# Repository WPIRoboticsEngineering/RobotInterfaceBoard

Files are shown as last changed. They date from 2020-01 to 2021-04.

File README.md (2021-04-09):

# Arduino and the ESP32 Toolchain and Sloeber Eclipse

This is installed on the lab machines already. 

Download and install this, do not change any default values

 [Sloeber Eclipse install instructions](https://github.com/WPIRoboticsEngineering/RobotInterfaceBoard/blob/master/InstallEclipse.md)

 [Instructions to Open Projects in Eclipse](https://github.com/WPIRoboticsEngineering/RobotInterfaceBoard/blob/master/UseEclipse.md)
 
 # Start a Fresh Arduino Sketch in Sloeber Eclipse
[Create a Sketch with Git (STRONGLY recommended)](StartFreshSketch.md)

[Create a Sketch without Git (Discouraged)](StartFreshSketchNOGIT.md)

# Install VSCode+PlatformIO

[Instructions for setting up VSCode for use in RBE1001](https://github.com/WPIRoboticsEngineering/ZenVSCodeInstaller)

# Robot Interface Board

The Robot Interface Board (RIB) is a breakout board for the [ESP32-DevKitC Arduino module](https://www.digikey.com/product-detail/en/ESP32-DEVKITC-32D/1965-1000-ND/9356990/?itemSeq=353617778). The Dev Kit C is a reference design of the ESP32-WROOM-32 module which houses the WiFi and bluetooth Antenae. The ESP32-WROOM-32 module houses an ESP32 microcontroller. 

#### Datasheet

[Arduino compatiple DevkitC]( https://esp-idf.readthedocs.io/en/latest/get-started/get-started-devkitc.html)

[ESP32 Microcontroller High level Datasheet, 61 pages]( https://www.espressif.com/sites/default/files/documentation/esp32_datasheet_en.pdf)

[ESP32 Microcontroller Detailed Datasheet, 669 pages]( https://www.espressif.com/sites/default/files/documentation/esp32_technical_reference_manual_en.pdf)

[ESP32-DevKitC Arduino module wireing diagram ](https://dl.espressif.com/dl/schematics/esp32_devkitc_v4-sch-20180607a.pdf)

## PCB

Image of Board

## ESP32Dev Board PINMAP

Pin Functions

## IO Pin counts

There are 16 I/O pins availible for use in your programs with no external perpheral already using them.

There are 21 I/O pins availible for use in your programs including the 5 output only strapping pins.

There are 27 I/O pins availible for use in your programs by reusing the boot button pin, serial pins and i2c pins for other purposes. 

## User Button

There is a button connected to pin 0 and is accessible to the users code as a button. If you hold it whild pressing the reset button, however, it will hold the chip in bootloader mode and it will not run your code until the core is reset or programmed over the USB. Once your code starts, this button is availible for use as a button in your code and pressing it will not effect the opperation of the core after your program has started.  

## Pins to Never Use because they will disrupt programming and opperation:

GPIO 6-11    - These pins are hookups for external system flash and are used by the system flash. Unless you are extending the chips flash capibilities, do not use these. 

GPIO 1 and 3 -  these are used to program the device and are serial port pins.

## Output Only Pins 

These pins are strapping pins for the core, if pulled to a different state than the default not boot.

These are strapping pins and have to be in known states at the time of the chip booting. If you use them as outputs, be careful to note the the pull up or down resistor states for each. When using these pins make sure the weak-pull resistor will not interfeare with your intended opperation, and do not add additional weak-pull resistors.

```
GPIO 2  (pull down)
GPIO 5  (pull up)
GPIO 12 (pull down)
GPIO 13 (pull up)
GPIO 15 (pull up)
```
## Input Only pins (No Pull ups availible, no output modes)

34-39 are input only. They have no output modes at all. Analog input and digital input are availible. Note that there are no input pullups on these pins. 

```
GPIO 35
GPIO 34
GPIO 39
GPIO 36
```

## Availible as Both Input and Output (Pull ups availible)

```
GPIO 4
GPIO 14
GPIO 16-19
GPIO 21-23
GPIO 25-27
GPIO 32-33
```
## External Use pins

GPIO 0 is the boot pin, if held low during a reset it will prevent the device from booting

GPIO 1 and 3 are the serial port used for programming and print statements. This should not be used for user functions, but can be used if serial functionality is needed.

GPIO 13 Has an LED connected to it on the RIB

GPIO 22 and 21 have 4.7kOhm pullups on them and are connected to the Wii accessory port. These can be used with other i2c devices.
See: https://github.com/acamilo/RobotInterfaceBoard/issues/31

GPIO 27 Is connected to the Wii header as controller detect. When the controller is connected, this is pulled to 3.3v. It is open when the controller is not connected.  

## Availible Servo/PWM/AnalogWrite Pins

The ESP32 can generate up to 16 simultanious Servo signels. 

```
GPIO 4     
GPIO 5    
GPIO 12-19 
GPIO 21-23 
GPIO 25-27 
GPIO 32-33 
```

## Servos, PWM, tone() and Timers

The library ESP32Servo deals with all of the issues of cross allocation of the 4 timers and the associated PWM channels.

Use ESP32Servo objects to control the servo

Use the tone() function provided by ESP32Servo to make tones with PWM's

Use ESP32PWM objects to deal with the sound, or the tone implementation provided inside of ESP32Servo.

The library provides examples for each.

FYI: Inside the library it deals with the allocation and de allocation of timers and the associations of PWM's with a common time base together. What you need to understand is that there are 4 timers. Each timer can produce 4 PWM's *at the same frequency* but with independent duty cycles. That means you can have 16 hardware controlled PWM, so long as you have no more than 4 different frequencies. Esp32Servo keeps track of the allocation states of the users PWMs and dynamically allocates the correct ledC channel.

### Timer Interrupts

To use a timer interrupt, you will want to tell ESP32PWM not to allocate a specific timer. 

```
ESP32PWM::timerCount[0]=4;// this disables timer 0
ESP32PWM::timerCount[2]=4;// this disables timer 2
```
The timer needs to be disabled before allocating any PWM's. After disabling it will not be used in the PWM allocation system and can be used by a library or by the user as a raw timer for interrupts. 

See https://techtutorialsx.com/2017/10/07/esp32-arduino-timer-interrupts/

### ledc functions

DO NOT USE THESE! These are raw API level and are for the pros only. These pure C functions are part of the IDF and are provided for ESP32 programmers that are not using Arduino framework. ESP32Servo uses these functions internally, but manages the interactions between channels for you. The ledc functions spread PWM generation across the timers 0-4 using channels 0-15 in an unintuitive pattern:

```
/*
 * LEDC Chan to Group/Channel/Timer Mapping
** ledc: 0  => Group: 0, Channel: 0, Timer: 0
** ledc: 1  => Group: 0, Channel: 1, Timer: 0
** ledc: 2  => Group: 0, Channel: 2, Timer: 1
** ledc: 3  => Group: 0, Channel: 3, Timer: 1
** ledc: 4  => Group: 0, Channel: 4, Timer: 2
** ledc: 5  => Group: 0, Channel: 5, Timer: 2
** ledc: 6  => Group: 0, Channel: 6, Timer: 3
** ledc: 7  => Group: 0, Channel: 7, Timer: 3
** ledc: 8  => Group: 1, Channel: 0, Timer: 0
** ledc: 9  => Group: 1, Channel: 1, Timer: 0
** ledc: 10 => Group: 1, Channel: 2, Timer: 1
** ledc: 11 => Group: 1, Channel: 3, Timer: 1
** ledc: 12 => Group: 1, Channel: 4, Timer: 2
** ledc: 13 => Group: 1, Channel: 5, Timer: 2
** ledc: 14 => Group: 1, Channel: 6, Timer: 3
** ledc: 15 => Group: 1, Channel: 7, Timer: 3
*/
```

Note that timer 0 is used for ledc channels 0, 1, 8, 9 and that those channels will be all effected if the frequency on timer 0 is changed. If you are writing some code that deals with LEDC, then do not use any features of ESP32Servo nor any library that uses timers. 

## Availible DAC pins
```
GPIO 25
GPIO 26
```
These pins when used with analogWrite will produce an 8 bit analog value on the given pin. The value is from 0-3.3v mapped to 0-255 values. The api is to simply use analogWrite().

## Interrupt

For code examples: https://techtutorialsx.com/2017/09/30/esp32-arduino-external-interrupts/

Availible interruptable pins are all input pins.

# Development Computer Options  

## Option 1) A lab machine

Availible to all students. 

Note that the driver is installed on these computers

Note that Arduino with the ESP32 toolchain is already installed in C:\WPIAPPS\arduino-1.8.3\

Note Eclipse is installed on all workstations with the Sloeber plugin installed. 

##  Option 2) Personal Machine

### Supported for this class

Windows 10 Pro 

A user name with no " " in the file path. Generally it is safe to use your WPI username as the username on your computer.

Fresh install is genearlly reccomended every 6 months. Install disk are availible to students as a resource from the WPI Helpdesk.

OneDrive and Dropbox conflict with the install process and must be fully removed from the user file paths. 

### Unsupported OS's

MacOS is unsupported and only intermittantly working. Drivers have been an issue with programming our board, and virtualization of Windows within OSX is tested non-working. If you have Mac OSX please install a fresh copy of Windows 10 nativly and dual boot. 

Ubuntu 16.04 is unsupported but works well.

Ubuntu 18.04 is unsupported but works well with some creative directions following. This will take more effort and would require pre-existing proficency in Linux. If you have 18.04 please install Windows 10 or 16.04. 

### How to get Windows 10 as a Student for free from WPI

To get your student copy of Windows go here: 

https://onlinestore.wpi.edu/

Select windows 10, and download it. For students you get one copy and it is free. 

You can follow this tutorial to install it:

https://www.youtube.com/watch?v=aTVOTY93XXU

# Arduino Libraries
## HOWTO
For detailed instructions on how libraries work, see: https://www.arduino.cc/en/Guide/Libraries

Open Arduino and select Sketch->Libraries -> Manage Libraries
## Which Libraries

### 1001

ESP32Servo

ESP32Encoder

### 2001
Search for and install:

ESP32Servo

ESP32Encoder

Esp32SimplePacketComs

SimplePacketComs

### 2002
Search for and install:

ESP32Servo

ESP32Encoder

Adafruit_BNO055

Adafruit Unified Sensor

Esp32SimplePacketComs

SimplePacketComs

DFRobotIRPosition

# FAQ and troubleshooting

### "I dont see 'ESP32 Dev Module' as an option in Arduino when I try to select my board..."

* Use a lab machine. This will not be a problem on the lab machines. 

* You need to install the ESP 32 toolchain. See https://github.com/WPIRoboticsEngineering/RobotInterfaceBoard#personal-computer-install-windows--supported

### "I can compile the code but I do not have a serial port option in Arduino..."

* Ensure the driver installed https://github.com/WPIRoboticsEngineering/RobotInterfaceBoard#personal-computer-install-windows--supported

* If its a MAC, this is the issue that causes us to say MacOS is UNSUPPORTED. Install Windows https://github.com/WPIRoboticsEngineering/RobotInterfaceBoard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

* Make sure the USB Micro cable is a data cable, not just a crappy USB charging cable with no data lines. 

### "I can select the correct serial port, put it wont program or times out while programming..."

* Program an example script using Lab computer   (if this works have them re-download the pre-packaged arduino from https://github.com/WPIRoboticsEngineering/RobotInterfaceBoard#personal-computer-install-windows--supported ) 

* Is the serial moniter open? Close it and try again. 

* Did it program earlier? Unplug the USB and plug it back in.

* Hold Boot button and Strobe the enable button to set core into bootloader mode. Try to program. (If this helps, you are printing too much data to the serial port)

* Unplug everything from all IO (If this fixes it, check the pins and voltages, also check for diode dead-shorts check https://github.com/WPIRoboticsEngineering/RobotInterfaceBoard#pins-to-never-use )

* Check to see if the processor or regulator is HOT. If it is, a dead-short or over-voltage event occured and the device is dead forever. Replace. 

### "I can program it but it but it keeps rebooting over and over..."

* Null pointers are the #1 cause of this behavior, use print statements to isolate the point where it reboots and check for null pointers. This is the issue 9 out of 10 times. 

* Interrupt issues - Interrupts that access memory that is used by non-interrupt code without a mutex or semiphore. Try disabling the interrupt and if this fixed the reboot issue, then go ahead and implement the mutex locking. 

* Something may also be plugged into one of the off-limits pins, or your code is reconfiguring and messing up one of these pins. See: https://github.com/WPIRoboticsEngineering/RobotInterfaceBoard#pins-to-never-use 

### "This processor seems more complicated than the Uno and the Mega, why are we using it?"

* The ESP32 is a faster core at 260Mhz, vs the 16Mhz Uno. It is also dual-core.

* It has more perpherals needed for building robots, 16x 12 bit ADC, 2x DAC and 16 hardware encoder perpherals

* It has hardware and software that support WiFi for communications. 

* 32 bit processing with an FPU means complex math is possible on the microcontroller. 

* It is Arduino compatible for programming and Library support

* It is an open source design of the DevKit-C module, using an open soruce tool-chain

### "My eclipse if giving a 'Salt needs to be 8 bytes' error

This error comes from different versions of eclipse fighting over the ```$HOME/.eclipse/``` folder. This folder is where the passwords and keys are stored, however other newer copies of Eclipse use a slightly different format. The two copies fight over control of htat folder. To fix the problem close all copies of Eclipse/Sloeber and then erase that folder. Open Sloeber again and password storage will begin working. 

### I logged in with my credentials but it's not working (and I have 2fa enabled on my GitHub account)

You need to generate a token and use that in place of a password when storing credentials in Sloeber. 

For instructions on creating a token see: https://help.github.com/en/github/authenticating-to-github/creating-a-personal-access-token-for-the-command-line

Use your username as the login ID, and the token in the password field.

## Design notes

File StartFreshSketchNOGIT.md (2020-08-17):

# Create new Arduino sketch
## From an example
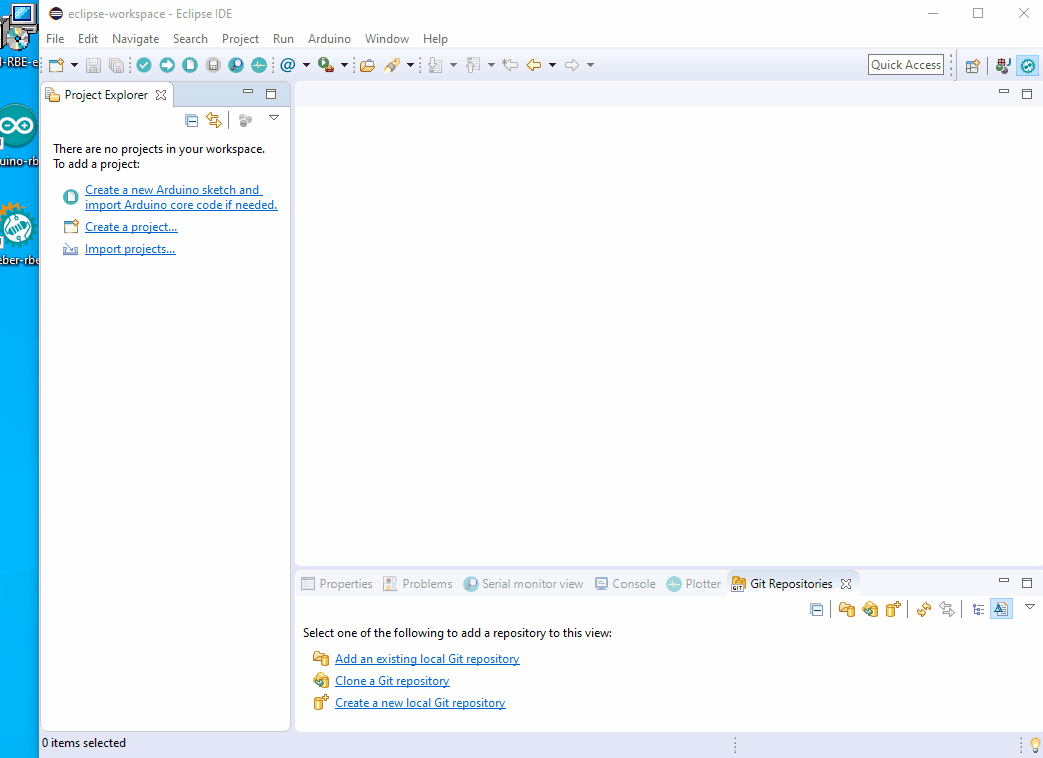
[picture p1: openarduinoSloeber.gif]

## Blank sketch


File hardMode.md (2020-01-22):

# HARD MODE

## Personal Computer install Linux   (Unsupported)

Ubuntu 18.04 Instructions:

[InstallToolchainOnUbuntu18-04.md](InstallToolchainOnUbuntu18-04.md)

Ubuntu 16.04 Instructions:
Installation instructions for Debian / Ubuntu OS
=================================================

- Install latest Arduino IDE from [arduino.cc](https://www.arduino.cc/en/Main/Software)
- Open Terminal and execute the following command (copy->paste and hit enter):

  ```bash
  sudo usermod -a -G dialout $USER && \
  sudo apt-get install git && \
  wget https://bootstrap.pypa.io/get-pip.py && \
  sudo python get-pip.py && \
  sudo pip install pyserial && \
  mkdir -p ~/Arduino/hardware/espressif && \
  cd ~/Arduino/hardware/espressif && \
  git clone https://github.com/espressif/arduino-esp32.git esp32 && \
  cd esp32 && \
  git checkout 1.0.3 && \
  git submodule update --init --recursive && \
  cd tools && \
  python3 get.py
  ```
- Restart Arduino IDE

- If you have Arduino installed to ~/, modify the installation as follows, beginning at `mkdir -p ~/Arduino/hardware`:

  ```bash
  cd ~/Arduino/hardware
  mkdir -p espressif && \
  cd espressif && \
  git clone https://github.com/espressif/arduino-esp32.git esp32 && \
  cd esp32 && \
  git checkout 1.0.3 && \
  git submodule update --init --recursive && \
  cd tools && \
  python3 get.py
  ```

## END Optional
-----

You most likely do not want to be here, but just in case you want to know how the sausage is made, here you go...

# Make Sure you have Java 8, *not 9, 10, 11 or 12*

Check your java version by opening CMD and typing 

```
java -version
```

and you should see:

```
java version "1.8.0_181"
Java(TM) SE Runtime Environment (build 1.8.0_181-b13)
Java HotSpot(TM) 64-Bit Server VM (build 25.181-b13, mixed mode)
```

If you see anything other than 1.8.something, remove Java then install it from:
  
https://www.java.com/en/download/manual.jsp  

Select this java on windows

## Install Eclipse and the Sloeber plugin (If the computer doesn't already have it)

Download the Eclipse Oxygen for C Development from here:

[https://www.eclipse.org/downloads/packages/release/2018-12/r](https://www.eclipse.org/downloads/packages/release/2018-12/r)

Select this Eclipse

Install Eclipse on C drive if using personal

```
C:\eclipse\
```

Once the install is done, open eclipse and go to the workbench. 




Open

```
Help->Eclipse Marketplace...
```

Search for Sloeber 



Set the workspace to Arduino mode. In the upper right hand corner there is a button with a little yellow plus sign, and when you hover over it is says "pen Perspective". Click that button. Select Arduino. 

Eclipse will restart to load the plugin.

#### Open the Arduino Preferences:

```
Arduino -> Preferences
```



And start by removing both of the default values for private Hardware and Private libraries:



Under Private Hardware Path, select New.. and search for (where you extracted Arduino)/hardware/ 

Mine looks like:
```
C:\WPIAPPS\arduino-1.8.3\hardware\
```

Under Private Library path, select New.. and search for your user library directory. It is usually in (your users home)\Documents\Arduino\libraries for Windows, or (your users home)/Arduino/libraries for Unix systems. You know you have the right one if the folder contains ESP32Servo, Esp32SimplePacketComs, SimplePacketComs, EspWii and WiiChuck Directories from the library install step above. Remember the location of this folder, it will be where you clone your code in a coming step. 

Mine looks like:
```
C:\Users\harrington\Documents\Arduino\libraries
```


# Doxygen and GraphViz
### Windows Doxygen and GraphViz

[Install Doxygen From these instructions](http://www.doxygen.nl/download.html)  or [the direct link](http://doxygen.nl/files/doxygen-1.8.15-setup.exe)

and [GraphViz from here](https://graphviz.gitlab.io/_pages/Download/Download_windows.html)

Then use [these instructins]( https://www.architectryan.com/2018/03/17/add-to-the-path-on-windows-10/) to set add GraphViz to the path

```
C:\Program Files (x86)\Graphviz2.38\bin
```

### Ubuntu Doxygen and GraphViz

```
sudo apt install doxygen
```
## After the native Doxygen, install the plugin

In eclipse

```
Help->Eclipse Marketplace...
```

Search for 

```
eclox
```

and install it. 

# Setup your project

 [Open Projects in Eclipse using the Eclipse instructions](https://github.com/WPIRoboticsEngineering/RobotInterfaceBoard/blob/master/UseEclipse.md)

# Troubleshooting

## arduinoPlugin\tools\make\make not found in PATH

There can be a currupted download to the Make tools, if this error comes up follow these instructions to correct it
Follow the instructions here : https://github.com/Sloeber/arduino-eclipse-plugin/issues/767

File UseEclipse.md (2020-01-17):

# First Install Eclipse/Sloeber/Doxygen 

 [See Eclipse install instructions in InstallEclipse.md](https://github.com/WPIRoboticsEngineering/RobotInterfaceBoard/blob/master/InstallEclipse.md)

# Set up an eclipse project

In eclipse, open 
```
Window->Show View-> Other -> Git ->Git Repositories
```


In the browser, Click the clone or download button in your new project and select clone (Be sure HTTPS not SSH is selected, unless you have set up your SSH keys).

 

Copy the clone URL.

In Eclipse, click the clone button: 

 

If your URL is still copied in the clip board, Eclipse will autofill most the clone information for the first step. Add your username and password.

 

Hit next and get to the Branch Selection window, change nothing and hit next.

Use the default checkout location. 

Hit Finish

## Open your project and start working

In Eclipse, Right click in the Project View and select 
```
New->Arduino Sketch
```

 

Un-check the default location, and seclect where you just cloned your code. Mine looks like: 

```
R:\RBE\gitRbe\RBE2001Code20
```

Give it the name:

```
RBE2001Code20
```
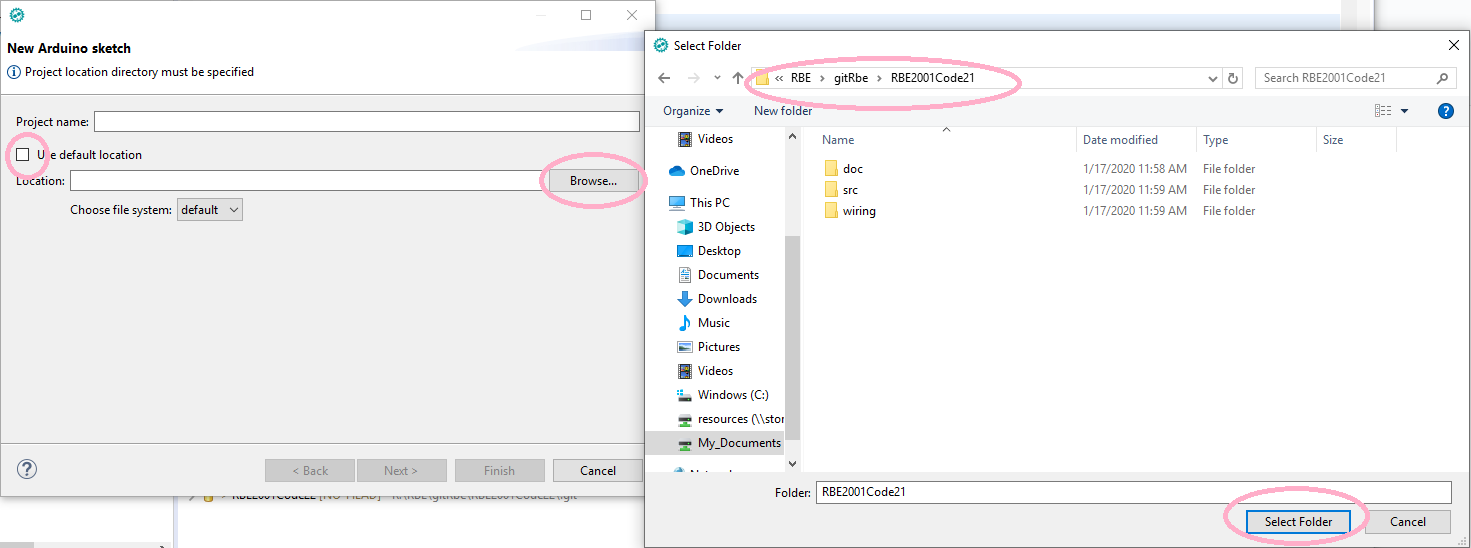
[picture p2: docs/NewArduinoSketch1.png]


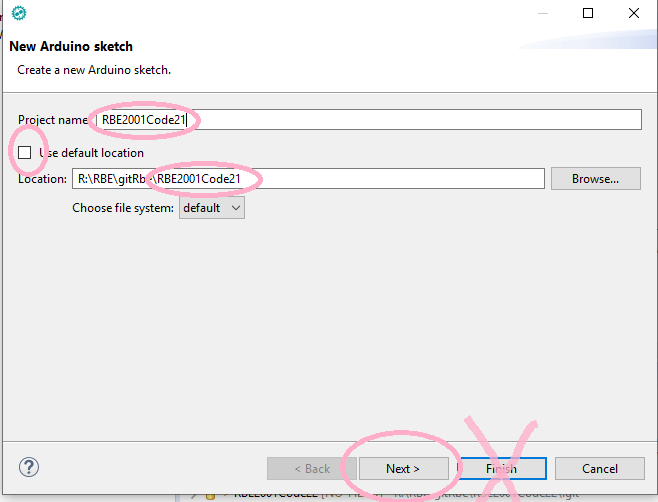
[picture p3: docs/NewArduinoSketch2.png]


Hit next then select the ESP32 toolchain. 



```
Board: ESP32 Dev Module
Upload Protocol: Default
Port (the port your device is on)
Core Debug Level: None
Flash Frequency 80mhz
Flash Mode: QIO
Flash Size: 4mb
Partition Scheme: Default
PSRAM: Disabled
Upload Speed: 921600
```

Then hit next and select Default ino file



Hit finish. 

Once the project shows up in Project Explorer tab, build index:



# Commit your changes

### Unfamiliar with Git?

run through this tutorial: https://resources.github.com/videos/github-best-practices/

Also check out this cheat sheet: http://overapi.com/git

### Familiar with Git?
When you make a change to any line of code, you should commit your changes. If you have worked for ~1 hour, then you should make a commit with a message describing your work. To do so, go back to 

Finally right click on your project
```
Team->Commit
```
Be sure to set the "Author" and "Committer" fields sould both contain the same data like this:
```
Kevin Harrington <harrington@wpi.edu>
```

Messages should consist of 60 charrectors of short description describing what changed, 2 new lines, then a t least one full sentance describing the justification for the change. If you have more than one file, only commit one at a time. using the "+" and "-" buttons in the Git Staging section. 

When you have chages to share with your team, first Right click on the repository and select "Pull". Merge any changes your team mates made and published to upstream. Then commit the merge (or commit nothing if the merge was clean) and push your changes to the upstream server.

Once you have pushed your changes, be sure to verify that they are on the GitHub.com website in Firefox. On your repository, go to
```
Insights->Network
```
and verify your changes are there. 

# Troubleshooting

## arduinoPlugin\tools\make\make not found in PATH

There can be a currupted download to the Make tools, if this error comes up follow these instructions to correct it
Follow the instructions here : https://github.com/Sloeber/arduino-eclipse-plugin/issues/767

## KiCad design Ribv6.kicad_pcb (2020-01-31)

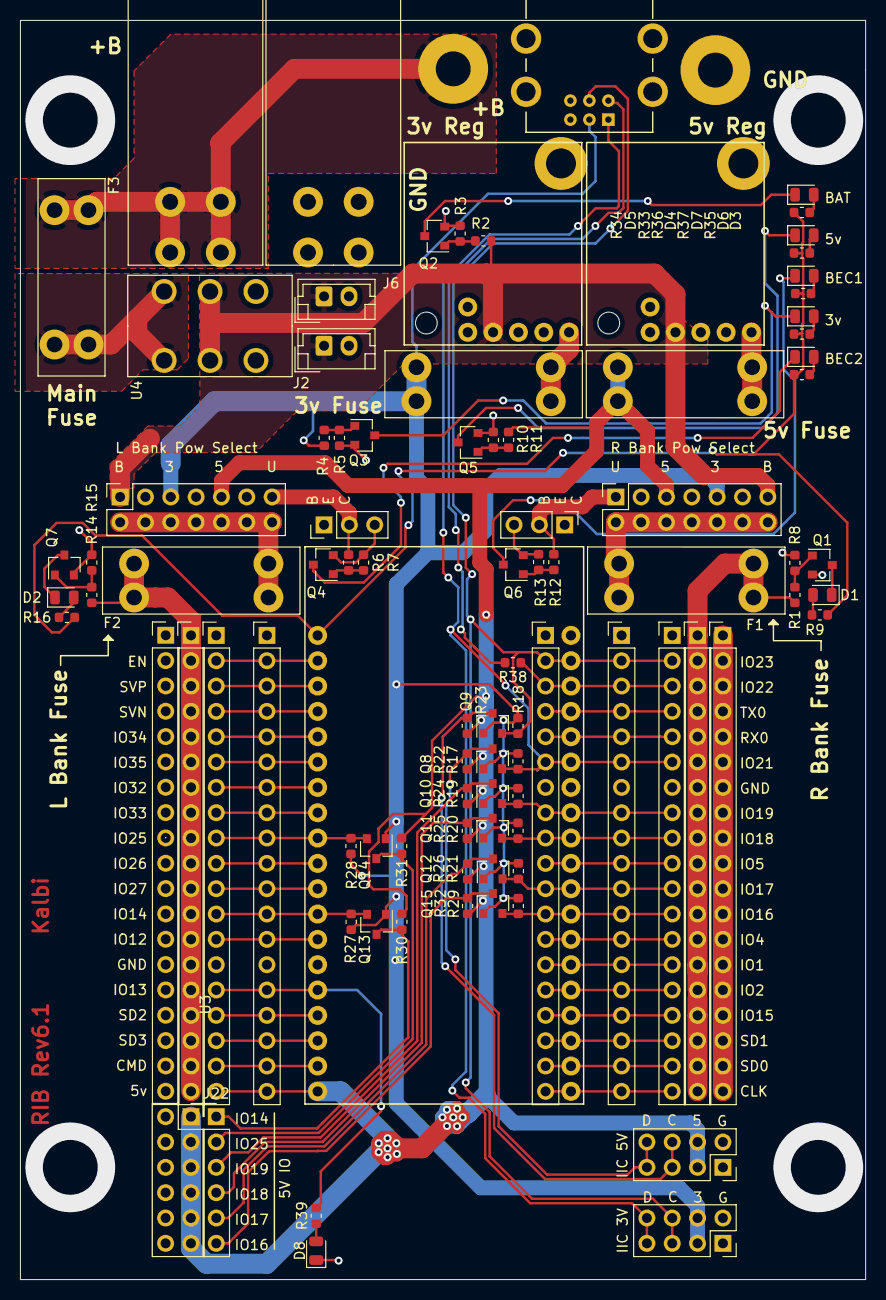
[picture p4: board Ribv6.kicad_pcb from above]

Board: 4 copper layers, 84.7 x 126.2 mm, 95 parts (0 on the bottom side), 80 nets.

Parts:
D1, D2, D3, D4, D5, D6, D7, D8: LED_Small; LED_0805_2012Metric
F1, F2, F3, F4, F5: Fuse; 3557-2
J1, J9: Conn_01x03; PinHeader_1x03_P2.54mm_Vertical
J2, J6: Conn_01x02_Female; JST_EH_B2B-EH-A_1x02_P2.50mm_Vertical
J3, J5, J7, J10, J13, J16, J19, J20, J21: Conn_01x19; PinHeader_1x19_P2.54mm_Vertical
J4, J8: Conn_02x07_Odd_Even; PinSocket_2x07_P2.54mm_Vertical
J11, J26: Conn_01x01_Male; P315100rH
J12, J24: Conn_01x01_Male; MountingHole_3.5mm_Pad
J14, J15: Conn_02x04_Odd_Even; PinSocket_2x04_P2.54mm_Vertical
J22: Conn_01x06; PinHeader_1x06_P2.54mm_Vertical
J23: Conn_02x06_Odd_Even; PinSocket_2x06_P2.54mm_Vertical
J25: Conn_01x06; CONN_WII
Q1, Q2, Q3, Q4, Q5, Q6, Q7, Q8, Q9, Q10, Q11, Q12, Q13, Q14, Q15: BSS138; SOT-23
R1, R2, R3, R4, R5, R6, R7, R8, R10, R11, R12, R13, R14, R15, R34: R_Small; R_0603_1608Metric
R9, R16, R33, R35, R36, R37, R39: 330; R_0603_1608Metric
R17, R18, R19, R20, R21, R22, R23, R24, R25, R26, R27, R28, R29, R30, R31, R32, R38: 10k; R_0603_1608Metric
U1, U2: polulu-3784-D36V28F7
U3: esp-devkit; ESP-DEVKIT
U4: DPDT_x2; GF-126-0327

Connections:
+3.3VA: R9.2, R16.2, R33.2, R34.2, R35.2, R36.2, R37.2, U3.3V3
+3V3: F4.2, J4.9, J8.5, J14.3, J14.4, J25.3, Q8.1, Q9.1, Q10.1, Q11.1, Q12.1, Q13.1, Q14.1, Q15.1, R4.2, R17.2, R18.2, R19.2, R20.2, R21.2, R27.2, R28.2, R29.2
+5V: F5.2, J4.5, J8.9, J13.19, J15.3, J15.4, J16.19, J23.1, J23.3, J23.5, J23.7, J23.9, J23.11, R10.2, R22.2, R23.2, R24.2, R25.2, R26.2, R30.2, R31.2, R32.2, U3.5V
+BATT: J2.1, J4.13, J6.1, J8.1, R2.2, U1.VIN, U2.VIN, U4.2, U4.5
GND: D8.1, J1.3, J2.2, J3.1, J3.2, J3.3, J3.4, J3.5, J3.6, J3.7, J3.8, J3.9, J3.10, J3.11, J3.12, J3.13, J3.14, J3.15, J3.16, J3.17, J3.18, J3.19, J6.2, J9.3, J10.1, J10.2, J10.3, J10.4, J10.5, J10.6, J10.7, J10.8, J10.9, J10.10, J10.11, J10.12, J10.13, J10.14, J10.15, J10.16, J10.17, J10.18, J10.19, J13.14, J14.1, J14.2, J15.1, J15.2, J16.14, J19.7, J20.7, J21.7, J23.2, J23.4, J23.6, J23.8, J23.10, J23.12, J24.1, J25.6, J26.1, Q1.2, Q2.2, Q3.2, Q4.2, Q5.2, Q6.2, Q7.2, R3.1, R5.1, R7.1, R8.1, R11.1, R13.1, R15.1, U1.GND, U2.GND, U3.GND
GPIO14: J13.12, J16.12, Q13.2, R27.1, U3.IO14
GPIO14_5: J22.1, Q13.3, R30.1
GPIO16: J19.12, J20.12, J21.12, Q15.2, R29.1, U3.IO16
GPIO16_5: J22.6, Q15.3, R32.1
GPIO17: J19.11, J20.11, J21.11, Q12.2, R21.1, U3.IO17
GPIO17_5: J22.5, Q12.3, R26.1
GPIO18: J19.9, J20.9, J21.9, Q11.2, R20.1, U3.IO18
GPIO18_5: J22.4, Q11.3, R25.1
GPIO19: J19.8, J20.8, J21.8, Q10.2, R19.1, U3.IO19
GPIO19_5: J22.3, Q10.3, R24.1
GPIO25: J13.9, J16.9, Q14.2, R28.1, U3.IO25
GPIO25_5: J22.2, Q14.3, R31.1
unnamed: D1.1, Q1.3
unnamed: D1.2, R9.1
unnamed: D2.1, Q7.3
unnamed: D2.2, R16.1
unnamed: D3.1, Q2.3
unnamed: D3.2, R35.1
unnamed: D4.1, Q3.3
unnamed: D4.2, R33.1
unnamed: D5.1, Q4.3
unnamed: D5.2, R34.1
unnamed: D6.1, Q5.3
unnamed: D6.2, R37.1
unnamed: D7.1, Q6.3
unnamed: D7.2, R36.1
unnamed: D8.2, R39.1
unnamed: F1.1, J4.2, J4.4, J4.6, J4.8, J4.10, J4.12, J4.14
unnamed: F2.1, J8.2, J8.4, J8.6, J8.8, J8.10, J8.12, J8.14
unnamed: F3.1, J11.1, J12.1
unnamed: F3.2, U4.3, U4.4
unnamed: F4.1, U1.VOUT
unnamed: F5.1, U2.VOUT
unnamed: J13.2, J16.2, U3.EN
unnamed: J13.3, J16.3, U3.SVP
unnamed: J13.4, J16.4, U3.SVN
unnamed: J13.5, J16.5, U3.IO34
unnamed: J13.6, J16.6, U3.IO35
unnamed: J13.7, J16.7, U3.IO32
unnamed: J13.8, J16.8, U3.IO33
unnamed: J13.10, J16.10, U3.IO26
unnamed: J13.11, J16.11, U3.IO27
unnamed: J13.13, J16.13, U3.IO12
unnamed: J13.15, J16.15, R39.2, U3.IO13
unnamed: J13.16, J16.16, U3.SD2
unnamed: J13.17, J16.17, U3.SD3
unnamed: J13.18, J16.18, U3.CMD
unnamed: J19.3, J20.3, J21.3, R38.1, U3.IO22
unnamed: J19.4, J20.4, J21.4, U3.TX0
unnamed: J19.5, J20.5, J21.5, U3.RX0
unnamed: J19.10, J20.10, J21.10, U3.IO5
unnamed: J19.13, J20.13, J21.13, U3.IO4
unnamed: J19.14, J20.14, J21.14, U3.IO1
unnamed: J19.15, J20.15, J21.15, U3.IO2
unnamed: J19.16, J20.16, J21.16, U3.IO15
unnamed: J19.17, J20.17, J21.17, U3.SD1
unnamed: J19.18, J20.18, J21.18, U3.SD0
unnamed: J19.19, J20.19, J21.19, U3.CLK
unnamed: Q1.1, R1.1, R8.2
unnamed: Q2.1, R2.1, R3.2
unnamed: Q3.1, R4.1, R5.2
unnamed: Q4.1, R6.1, R7.2
unnamed: Q5.1, R10.1, R11.2
unnamed: Q6.1, R12.1, R13.2
unnamed: Q7.1, R14.1, R15.2
unnamed: U4.1, U4.6
Rail1: F1.2, J5.1, J5.2, J5.3, J5.4, J5.5, J5.6, J5.7, J5.8, J5.9, J5.10, J5.11, J5.12, J5.13, J5.14, J5.15, J5.16, J5.17, J5.18, J5.19, R1.2
Rail2: F2.2, J7.1, J7.2, J7.3, J7.4, J7.5, J7.6, J7.7, J7.8, J7.9, J7.10, J7.11, J7.12, J7.13, J7.14, J7.15, J7.16, J7.17, J7.18, J7.19, R14.2
SCL_5: J15.5, J15.6, Q9.3, R23.1
SCL_33: J14.5, J14.6, J19.2, J20.2, J21.2, J25.4, Q9.2, R18.1, U3.IO23
SDA_5: J15.7, J15.8, Q8.3, R22.1
SDA_33: J14.7, J14.8, J19.6, J20.6, J21.6, J25.1, Q8.2, R17.1, U3.IO21
UBEC1: J1.2, J4.1, R12.2
UBEC2: J8.13, J9.2, R6.2
prez: J25.2, R38.2

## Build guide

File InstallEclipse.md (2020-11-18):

# Easy Mode
Download and install these, do not change any default values

## [Officially Supported Choice] 
### Windows 10 Stand Alone install

Requirements: Windows 10 on x86_64 with 16gb Ram

Development Environment: [Sloeber Windows Installer 0.3.2](https://github.com/WPIRoboticsEngineering/ESP32ArduinoEclipseInstaller/releases/download/0.3.2/WPI-RBE-esp32-0.3.2.exe)

Driver: [Esp32 Driver Windows](https://github.com/WPIRoboticsEngineering/ESP32ArduinoEclipseInstaller/releases/download/0.0.0/CP210x_Universal_Windows_Driver.zip)

Unzip the contents.

Open the folder on your disk and run

```
CP210xVCPInstaller_x64.exe
```

## [Unofficially supported] 
### Linux Bundled Sloeber

Development Environment: [Sloeber Linux Stand Alone](https://github.com/WPIRoboticsEngineering/ESP32ArduinoEclipseInstaller/releases/download/0.0.0/linux-eclipse-esp32.sh)

## [Unofficially supported] 
### MacOS 10.14 or earlier Bundled Sloeber

We reccomend you install Windows 10 with boot camp. If you want to try the native MacOS version, here be dragons.

Development Environment: [Sloeber MacOS Stand Alone](https://github.com/WPIRoboticsEngineering/ESP32ArduinoEclipseInstaller/releases/download/0.1.9/sloeber-MacOS-Esp32.zip)

Driver: [Esp32 Driver MacOS](https://github.com/WPIRoboticsEngineering/ESP32ArduinoEclipseInstaller/releases/download/0.0.0/SiLabsUSBDriverDisk.dmg)

## Thats it, its all installed and configured

You are done, do not continue, go here:

## Start a Fresh Arduino Sketch
[Create a Sketch with Git ](StartFreshSketch.md)

[Create a Sketch no version control](StartFreshSketchNOGIT.md)
 
 Or just open Arduino RBE config on your desktop and use as normal. 

# HARD MODE

## [Unsupported, not reccomended] 
### MacOS 10.15+ Bundled Sloeber

We reccomend you install Windows 10 with boot camp. If you want to try the native MacOS version, here be dragons.

#### 1) Install Standard Java 8

First install Java: https://www.java.com/en/download/manual.jsp

#### 2) Install the OpenJDK Framework

https://github.com/AdoptOpenJDK/openjdk8-binaries/releases/download/jdk8u262-b10/OpenJDK8U-jdk_x64_mac_hotspot_8u262b10.pkg

GUI installation

Instructions for running an interactive installation using the macOS PKG installer.

1. Download the .pkg file.

2. Navigate to the folder that contains the file and open it to launch the installation program or drag the icon to your Application folder.

3. The Introduction screen indicates the target location for the installation, which you can change later in the install process. Click Continue.

4. Read the license, click Continue and accept the license if you are happy with the terms.

5. Change the target location for the installation. Click Install to complete the installation.

#### 3) Install Sloeber and the Driver

Development Environment: [Sloeber MacOS Stand Alone](https://github.com/WPIRoboticsEngineering/ESP32ArduinoEclipseInstaller/releases/download/0.1.9/sloeber-MacOS-Esp32.zip)

Driver: [Esp32 Driver MacOS](https://github.com/WPIRoboticsEngineering/ESP32ArduinoEclipseInstaller/releases/download/0.0.0/SiLabsUSBDriverDisk.dmg)

## From scratch setup

I am almost sure you do not want this, but in case you are curious how those bundles are created in the first place you can look at [hardMode.md](hardMode.md)

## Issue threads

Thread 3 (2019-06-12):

Update power system for RIB

madhephaestus, 2019-06-12:
Update of rib need not maintain the board outline nor bolt pattern. Use the check boxes to keep track of progress.
@acamilo

- [x] Bolt holes should be 5.5mm diameter, keepaway of 9mm diameter
- [x] Bolt holes should lie on a 25mm grid
- [x] Add a rail, one unit inboard of the Devkit-c, to allow the narrow version of the module to be used
- [x] 7.5 - 18 v battery in, with a solder lug and
- [x] banana plug for power and ground (RAW)
- [ ] Side of board with the banana plugs should be ~80mm, with the bolt holes at 75mm center-to-center
- [x] A 5v 2 amp switching converter, RAW (post fuse) in ,  powering the ESP (SYSTEM 5)
- [x] 2 x external power converter ports, RAW (post fuse) in , regulated out, connectors to match the OTS switch mode we use (EXT REG)
- [x] 3.3v, 2 amp sensor power, replace the 3.3 from ESP pins (SENSOR 3.3)
- [x] replace the 3.3 from ESP pins with SENSOR 3.3
- [x] both rails should have a power switch jumper bank, from rail to: SYSTEM 5,RAW,EXT REG,SENSOR 3.3
- [ ] each power bank should have an indicator led for each 4 power rails, total 8 leds, physically close to the associated rail.
- [ ] New Images, use the same names to keep documentation links consistent
- [x] connect GPIO 0 (BOOT) to the IO
- [x] connect RST to IO
- [x] add a 5v level shiftier to i2c and expose the 5v side in a header
- [x] add 5v level shifted (bi directional) versions of 19,18,17,16,25,14
- [x] 5v bank should be similar to io bank, 8x3 0.1 in female headers, signel,  (SYSTEM 5), ground
- [ ] add SS on the outer edge of the IO, improve readability

madhephaestus, 2019-06-13:
@acamilo please use this issue number in your commit messages to link them here

acamilo, 2019-06-24:
- [ ] 7/1/2019 Send prototype to pcb house
- [ ] 7/8/2019 Begin assembly, testing, bugfixes
- [ ] 7/15/2019 Send out next rev
- [ ] 7/22/2019 assy,testing rev2
- [ ] 7/29/2019 start full turn order of 30

acamilo, 2019-06-24:
each power bank should have an indicator led for each 4 power rails, total 8 leds, physically close to the associated rail.

Why do we need a power indicator for each rail and each voltage?

madhephaestus, 2019-06-24:
@acamilo the power indicators were asked for specifically.

Closed 2020-01-17.

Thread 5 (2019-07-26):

Rib V2 needs a switch

madhephaestus, 2019-07-26:
As an extension of #3

madhephaestus, 2019-07-27:
the switch should disconnect the battery from the rest of the circuit. When off, the batter should not drain.

acamilo, 2019-10-15:
ok

Closed 2020-01-17.

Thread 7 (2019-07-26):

Rib v2 Banana Jacks should be color coded, red for Positive

madhephaestus, 2019-07-26:

acamilo, 2019-10-15:
This is a change to the BOM. The test board was populated with black because that is what was ordered.

madhephaestus, 2019-10-15:
commit the change to the BOM and close the issue

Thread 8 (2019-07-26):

BEC headers should match the BEC

madhephaestus, 2019-07-26:
on header should be 2 pin keyed female, the other a 3 pin male.

acamilo, 2019-10-15:
I can not source the 2 pin keyed connectors.

madhephaestus, 2019-10-15:
https://www.pololu.com/product/2181

madhephaestus, 2019-10-15:
also https://www.digikey.com/catalog/en/partgroup/rcy-series/25502

acamilo, 2019-10-18:
Free hanging, goes on the end of a cable.

acamilo, 2019-10-18:
Also, the 2181 is a "male" but it is the end thats on the UBEC side.

acamilo, 2019-10-18:
i recomend an adapter cable to something sensable.

acamilo, 2019-10-18:
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
like this JST

acamilo, 2019-10-18:
I move forward with a PTH JST style connector and you have some students make and heat shrink a few short cables.

madhephaestus, 2019-10-18:
just leave unpopulated and we can solder one of these on: https://www.pololu.com/product/2180

acamilo, 2019-10-18:
I don't like danglers

acamilo, 2020-01-17:
If we're going with a dangler then this issue is closed.

Closed 2020-01-17.

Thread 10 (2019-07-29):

Rib v2 D1 is always off, regardless of fuse and jumper

madhephaestus, 2019-07-29:

acamilo, 2019-10-15:
There is a problem with the footprint for the P-CH MOSFET. I will probably just use the circuit i used for the power lights.

Closed 2020-01-17.

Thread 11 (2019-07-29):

Rib v2 Jumper bank is half unlabeled, confusing

madhephaestus, 2019-07-29:
There are 7 jumper configurations, 4 lables, this is confusing

acamilo, 2019-10-15:
This is intentional. Everything is spaced out so that you can't put the jumper in sideways and short two rails together. I could silkscreen an X in there.

madhephaestus, 2019-10-15:
ok, then make them seperate 2 pin headers then.

madhephaestus, 2020-01-17:
Better idea:
Alternate source, rail pins instead of making one row the sources and one row the rail. If you alternate per pin, then every source pin is surrounded by rail pins no matter how the user plugs in the jumper.

Error free jumping can be done with a 4x2 -  0.1in header.

Row one:

5v, rail, HC5v, rail, ext

Row Two:

rail, 3.3v,rail,raw, rail

madhephaestus, 2020-01-17:
Alternate the labels also to give more room for each and place the label near that actual voltage.

acamilo, 2020-01-17:
This will make the routing needlessly complicated. What are the benefits of this design over the current one and how do they justify the more complex layout.

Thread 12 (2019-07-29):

Power Lugs and power banana are missing labels

madhephaestus, 2019-07-29:
The solder lugs have no power labels
the bananna jacks have no lables

labels should indicate acceptable voltage range

acamilo, 2019-10-15:
ok, makes sense.

acamilo, 2020-01-17:
fixed in d77f626

Closed 2020-01-17.

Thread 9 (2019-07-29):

RIB v2 D9 is always on, regardless of fuse/jumper

madhephaestus, 2019-07-29:

acamilo, 2019-10-15:
There is a problem with the footprint for the P-CH MOSFET. I tried to fix this one. I will probably just use the circuit i used for the power lights.

Closed 2020-01-17.

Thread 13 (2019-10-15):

Components for new RIB missing from Odoo

madhephaestus, 2019-10-15:
the components such as the specific BEC connector and the correct length headers are missing out of odoo.

acamilo, 2019-10-15:
ok

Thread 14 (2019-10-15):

Add a hole dead center to the power supplies, **not in line** with the supplies mount hole

madhephaestus, 2019-10-15:
I want to put a supporting block under the power supplies. I need a hole under the supply, **but not in line with the supplies hole**. This hole should be 3.1mm diameter. This block will have its own fastener, with a second fastener holding the supply. This will make the replacement easier and the assembly less fiddly.

acamilo, 2019-10-15:
I don't understand this request. There is already a hole for a standoff under each supply module.

madhephaestus, 2019-10-15:
the hole on the board is in line with the mount holes on the power supply. Not that, anywhere else but that

acamilo, 2019-10-16:
I understand what but not why. what plan do you have for mounting the supplies? i was going to use a standoff and a screw.

madhephaestus, 2019-10-16:
there will be a small printed block with a hole and countersunk head that mounts through the RBO to the case. the block will have a threaded hole that the supply mounts to. As it gets bumped over time the standoffs come loose (or are threadlocker and are hard to remove) and with a screw from below, would require disassembly of the case to tighten the screw again.

acamilo, 2019-10-16:
I don't like this because it covers the chips. With a standoff we would have airflow.

acamilo, 2019-10-16:
thoughts on something like this?
https://www.adafruit.com/product/4207

madhephaestus, 2019-10-16:
Measure the distance with a caliper, make sure that the exact height we need exists. if so, the solderable ones look good.

acamilo, 2020-01-17:
We will use the solder-able standoff.

Closed 2020-01-17.

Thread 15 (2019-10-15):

I need an svg or JSON of the board outline and mount holes

madhephaestus, 2019-10-15:
To make the case i need the board outline and mount holes, and relative locations of the externally interfacing components.

An SVG with each component as a layer would work well.

Alternantly, if you wanted to define some sort of .json format for objects and mount holes, ill make a case generator script which may be useful on future projects.

acamilo, 2019-10-15:
ok, makes sense.

madhephaestus, 2020-01-17:
No progress

madhephaestus, 2020-01-17:
I need the data format FIXED

I need the json file to have the dimentions of the board rectangle fields and the location of the centroids of the bolt holes, as well as bolt hole diameter. The rectangle is measured as Positive x and positive Y only. If looking from the top down the 0,0 in xy is the bottom left.

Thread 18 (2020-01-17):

[FEATURE ADD] v2 add sockets for the pololu motors

madhephaestus, 2020-01-17:
The power side will come from the socketed in h-bridges. The encoder lines need to be run through the level shifters according to the existing wiring:

Be sure to *MATCH* the pinout defined in the documentation and this header file:

https://github.com/WPIRoboticsEngineering/RBE2001_template/blob/master/config.h

*NO SUBSTITUTIONS*

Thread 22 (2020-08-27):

pin 0 -- pullup or not?

gcl8a, 2020-08-27:
Does pin 0 have an external pullup? It seems to make no difference whether I declare it as INPUT or INPUT_PULLUP. For reference, I want to use it as user interface (eg, to start counting).

madhephaestus, 2020-08-27:
it does not have a pullup, *BUT* on normal boot it is set to INPUT_PULLUP, however on a reset it doesnt go through the same code and will come up without the pullup. It is always best practice to use the pullup explicitly.

Closed 2020-08-27.
